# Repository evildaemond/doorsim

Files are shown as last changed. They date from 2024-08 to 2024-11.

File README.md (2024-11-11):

# doorsim

The DoorSim is a Open Source PACS (Physical Access Control System) built for research, training, and CTFs on RFID and Physical Security. 

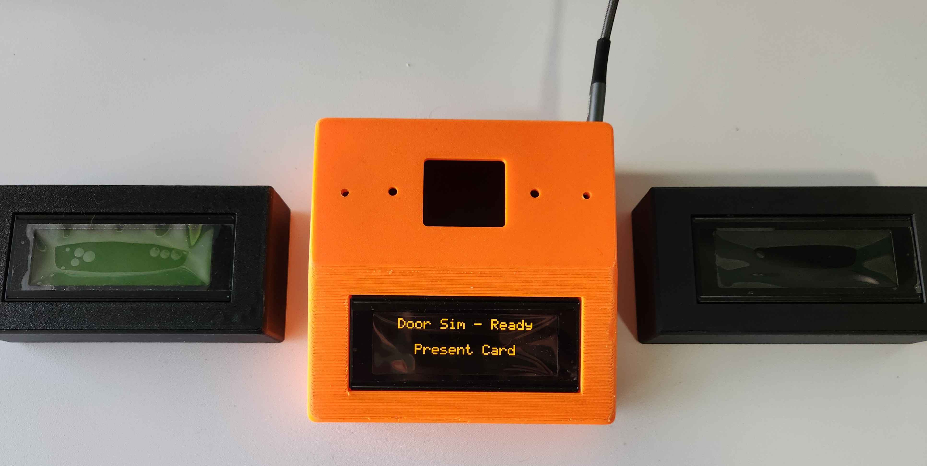
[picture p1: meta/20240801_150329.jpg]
doorsim


## Features

- Custom PCB with ESP32 Base
- Wiegand interface with Industry Standard Connectors
- 2004a Display for Ease of Reading
- Web Interface for Card/Event Reading and Settings
- Inbuilt CTF Mode with event logs
- USB-C PD Power Supply
- Expandable GPIO
- Multiple 3d Printed Desktop Reader Cases

## Bill of Materials

### PCB

|Quantity|Name|Link|
|---|---|---|
|1|PCB|Repo Link|
|1|ESP32-WROOM-32D Development Board|<https://www.aliexpress.com/item/1005006476877078.html>|
|1|2004A Display (Bare without i2c converter)|<https://www.aliexpress.com/item/1005005973980073.html?spm=a2g0o.order_list.order_list_main.22.3d051802PKVqRJ>|
|1|USB-C PD Trigger Board|<https://www.aliexpress.com/item/1005004381460387.html>|
|3|5.0-2P Screw Terminal Blocks|<https://www.lcsc.com/product-detail/Screw-terminal_Cixi-Kefa-Elec-KF332K-5-0-2P_C474889.html>|
|1|2.54mm 1x16 male-male header pins|<https://www.aliexpress.com/item/1005001514058091.html>|

### Cases

#### Handheld Version

|Quantity|Name|Link|
|---|---|---|
|1|Case Body||
|1|Case Bottom||
|2|M3 Standard CNC Kitchen Threaded Insert|https://cnckitchen.store/products/gewindeeinsatz-threaded-insert-m3-standard-100-stk-pcs|
|4|M4 Standard CNC Kitchen Threaded Insert|https://cnckitchen.store/products/gewindeeinsatz-threaded-insert-m4-standard-50-stk-pcs|
|4|M3x10 Round Head Screw||
|2|M4x10 Flat Head Screw||

#### All Others

|Quantity|Name|Link|
|---|---|---|
|1|Case Body||
|1|Case Bottom||
|2|M3 Standard CNC Kitchen Threaded Insert|https://cnckitchen.store/products/gewindeeinsatz-threaded-insert-m3-standard-100-stk-pcs|
|4|M4 Standard CNC Kitchen Threaded Insert|https://cnckitchen.store/products/gewindeeinsatz-threaded-insert-m4-standard-50-stk-pcs|
|2|M3 Nut||
|2|M3x12 Flat Head Screw||
|4|M3x10 Round Head Screw||
|4|M4x10 Flat Head Screw||

### RFID Reader

The design of the DoorSim at this stage means you can use any RFID Reader which supports Wiegand Output. The only difference will be the 3d printed case you house the doorsim in, only if you intend to use it as a non-handheld version. 

## Build Steps

### Soldering

Soldering guide assumes minimal soldering experience and only through hole construction

1. Collect all required items in Main Board Bill of Materials
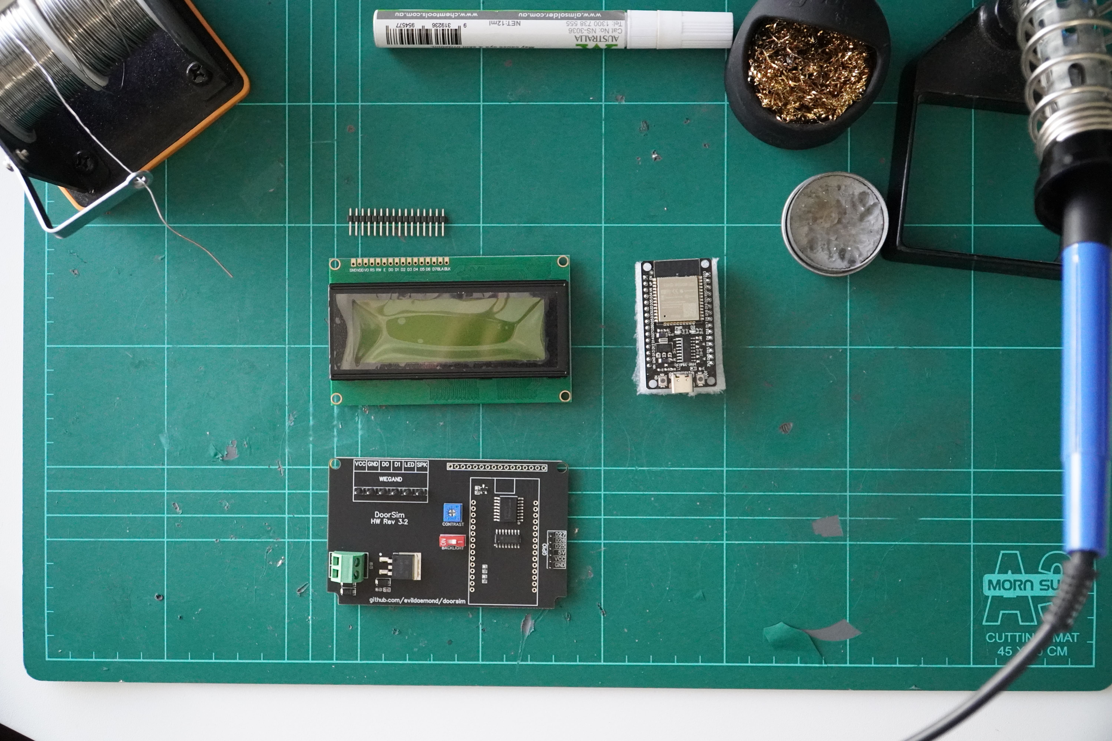
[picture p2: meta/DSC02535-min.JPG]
step1

1. Insert legs of the ESP32-WROOM-32D Development Board into PCB
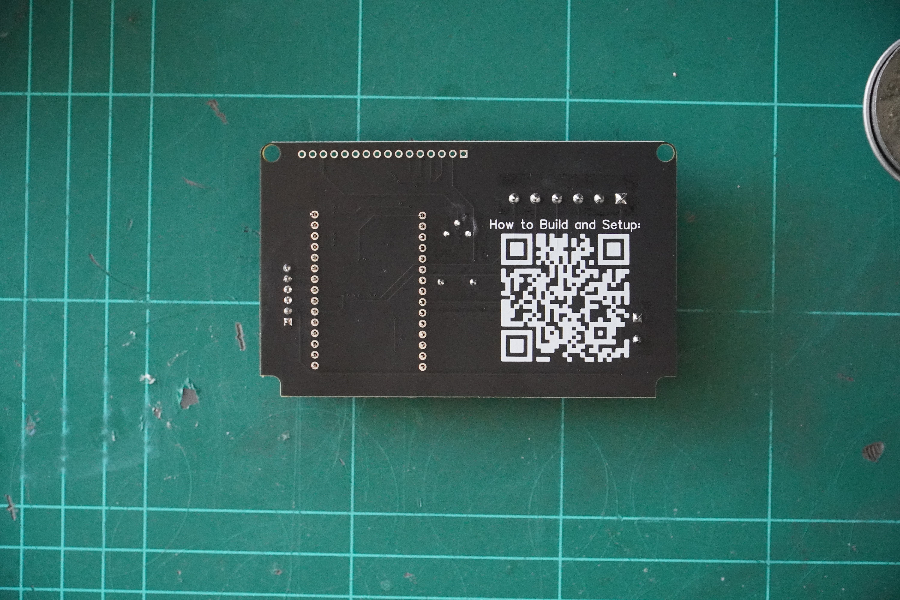
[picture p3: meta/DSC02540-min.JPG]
step2

1. Apply flux and solder legs in place, apply light pressure from the back on the development board and start at each corner, try to keep the board flat
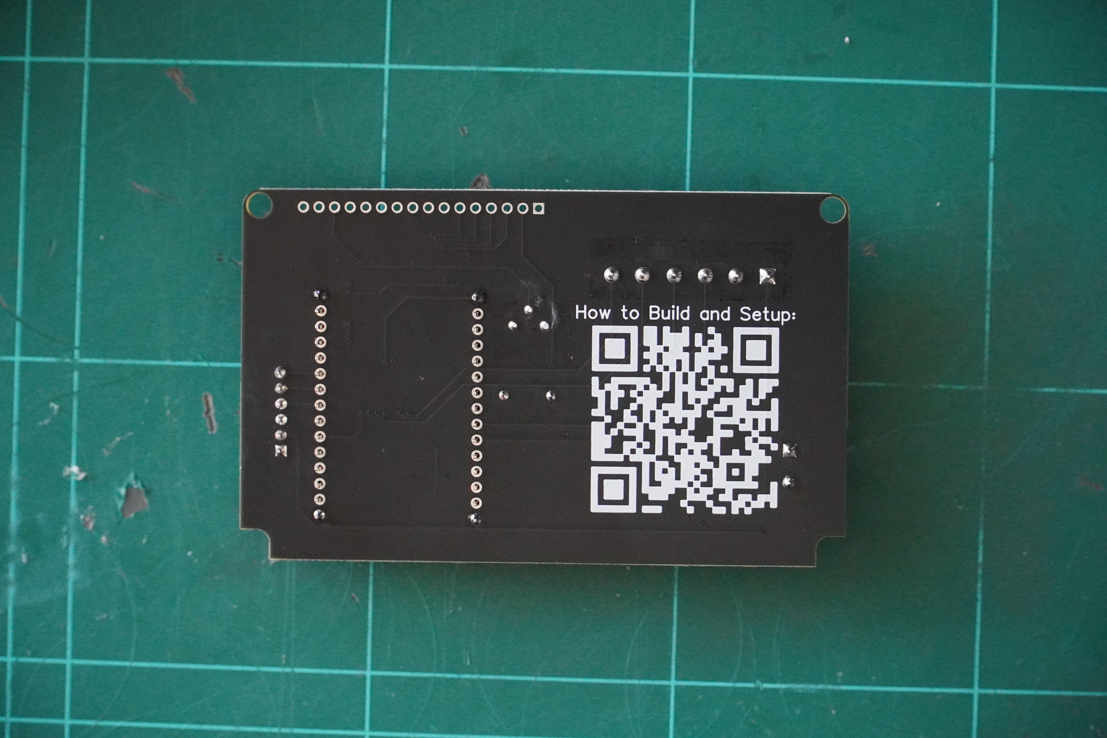
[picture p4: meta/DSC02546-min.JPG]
step3

1. Trim down the pins legs to roughly 2mm (078740157 Inches) and clean any leftover residue lightly with isopropyl alcohol and a old toothbrush
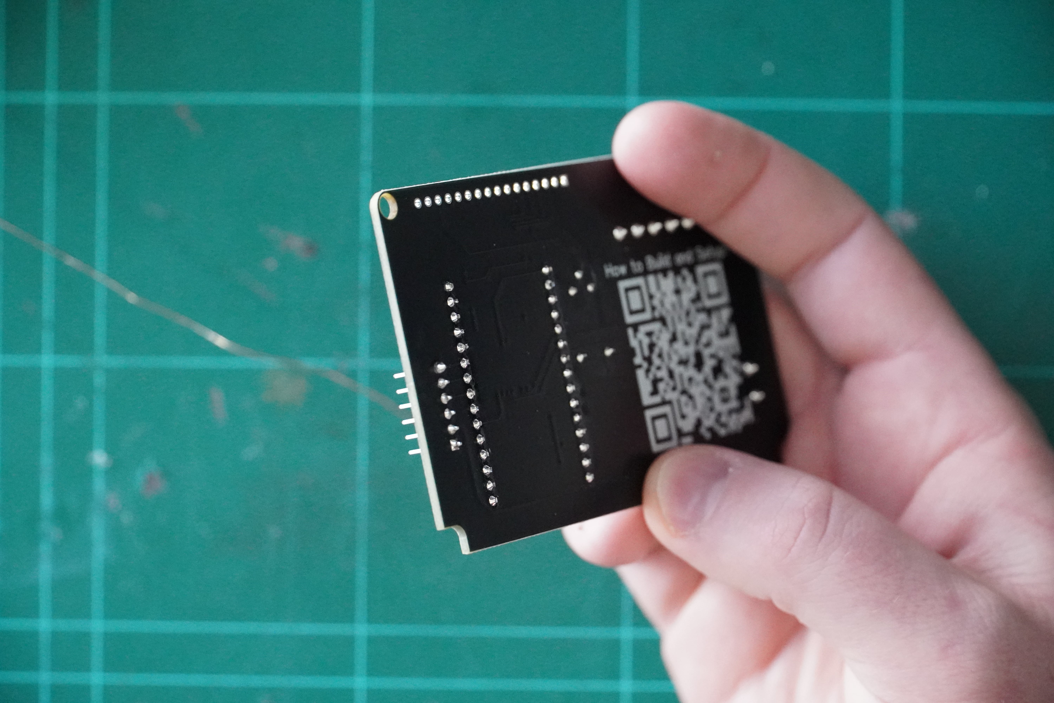
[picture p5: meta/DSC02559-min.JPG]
step4

1. Fit the male-to-male header pins between the 2004a display and the PCB, with the longer side facing up
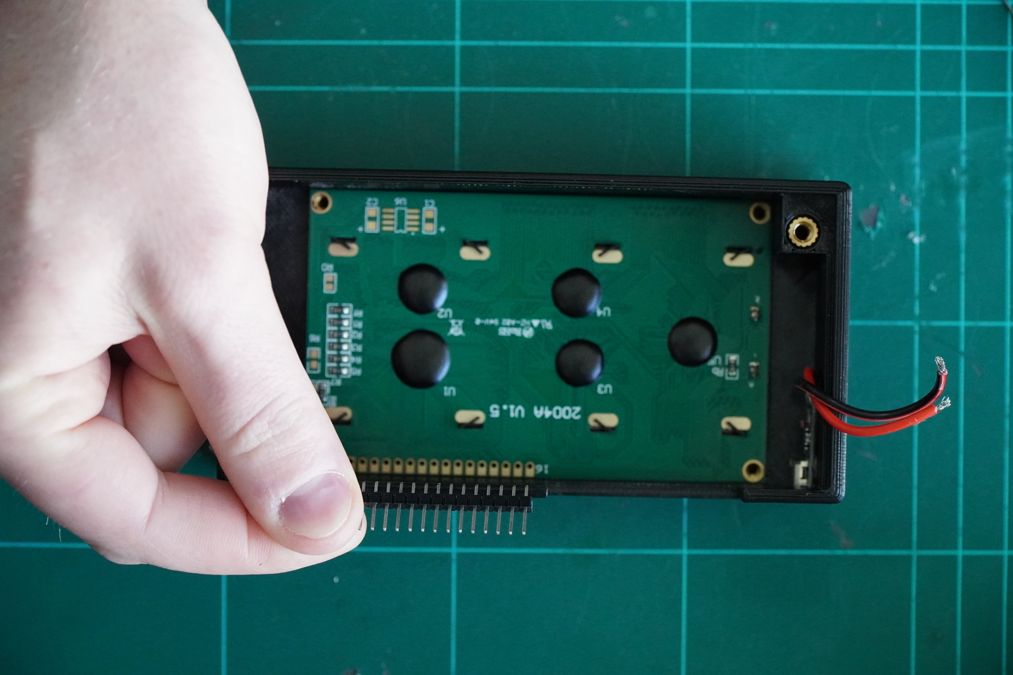
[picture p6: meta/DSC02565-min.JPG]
step5

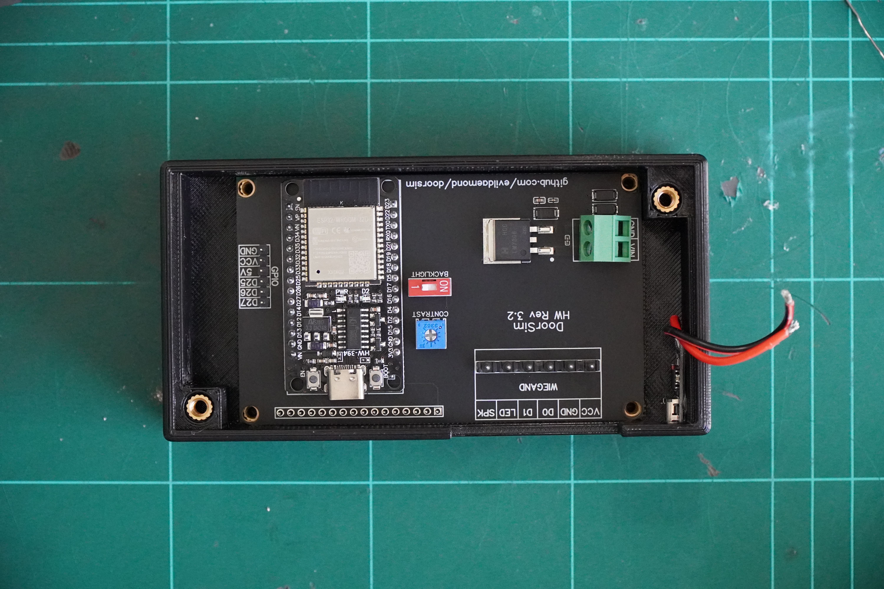
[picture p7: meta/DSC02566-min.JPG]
step6

1. Applying pressure to the left and top sides of the PCB and 2004a display, apply flux and solder the 2 pins of the opposing sides on the PCB. 
    1. Hint: They should be alligned with the holes on the board
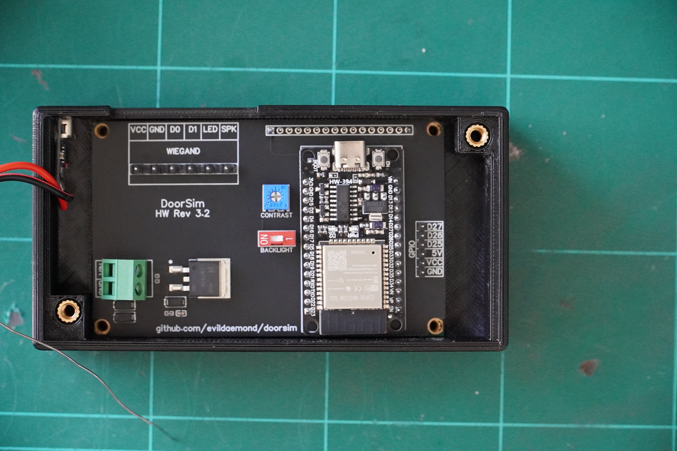
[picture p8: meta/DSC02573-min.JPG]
step7

1. Flip over the board, applying pressure on the same sides, and do the same on the 2004a display side.
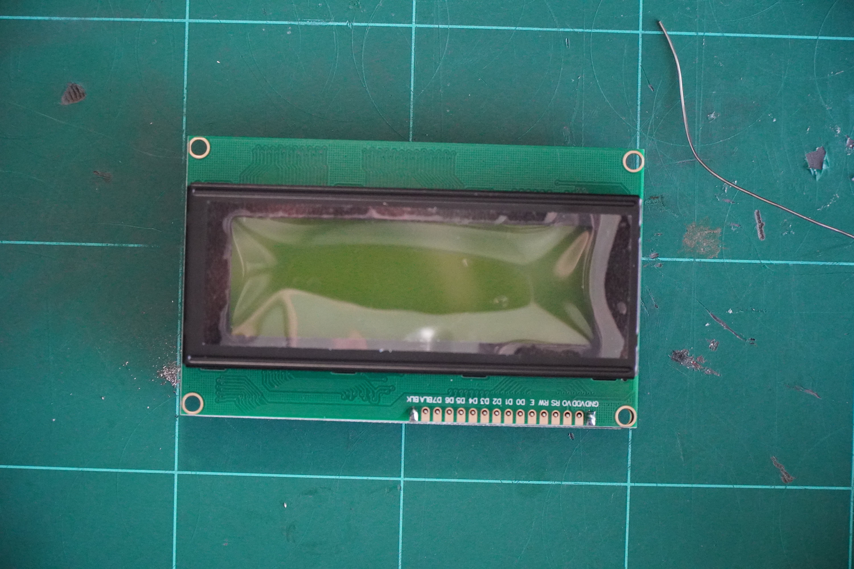
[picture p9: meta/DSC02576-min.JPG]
step8

1. Solder in the rest of the pins on both the display and PCB
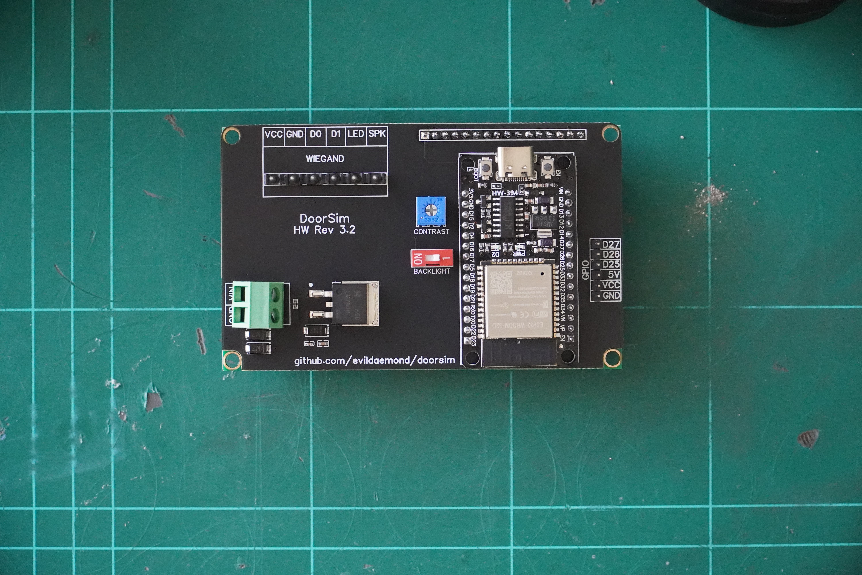
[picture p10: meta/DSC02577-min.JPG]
step9

1. Trim the PCB Side of the pin legs to roughly 2mm (078740157 Inches) and clean any leftover residue lightly with isopropyl alcohol and a old toothbrush
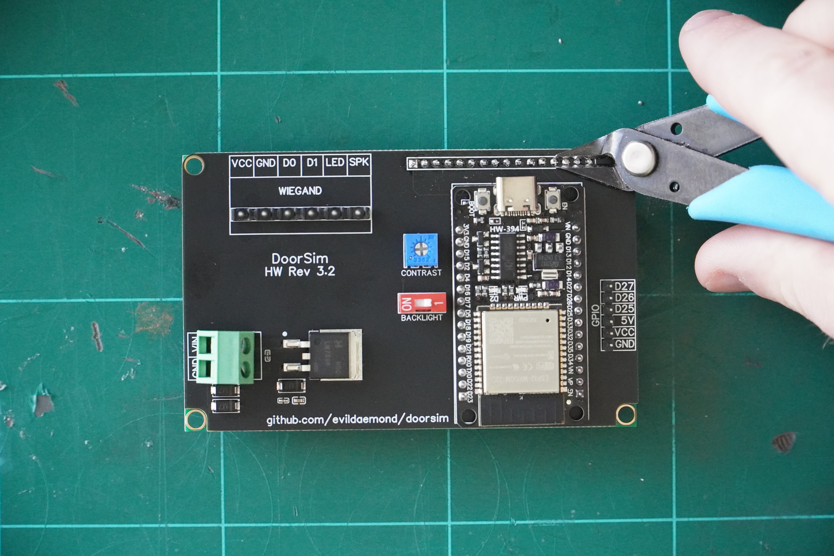
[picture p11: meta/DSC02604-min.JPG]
step10

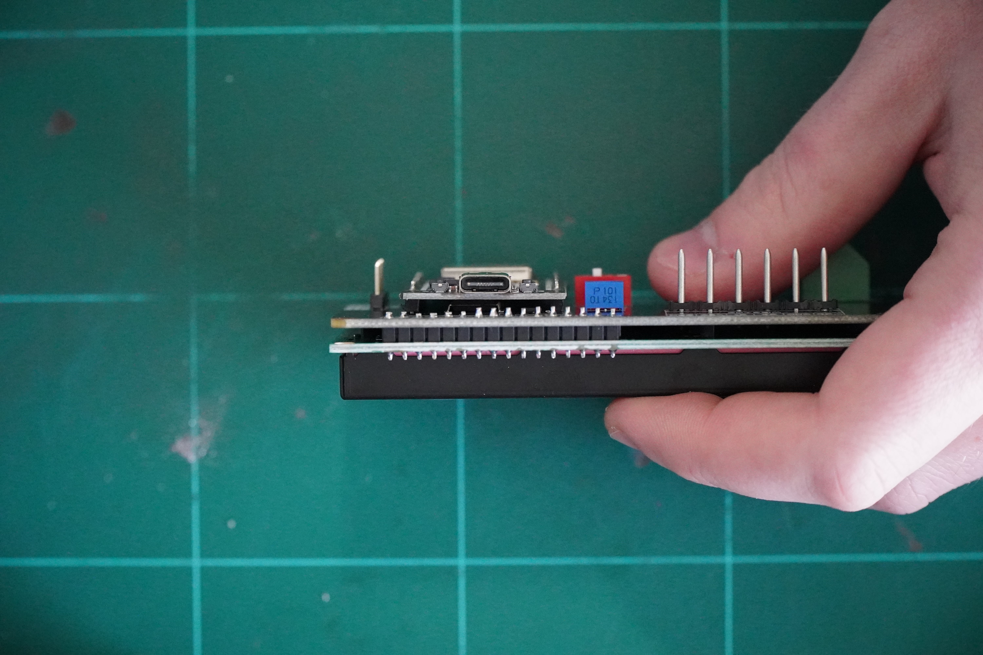
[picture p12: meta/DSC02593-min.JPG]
step11

1. *Optional:* In some cases, you may need to trim or elongate the wires for the USB-PD Connector, recommendation is to measure and cut, remove old wire connectors from board, and tin the ends before inserting and screwing into terminal connectors

### Case

1. Using the M3 Standard Threaded Insert, insert 4 into the 2004a Display hole, applying with a soldering iron, try to keep it straight up as you insert, applying light pressure
    1. Hint: Using a set of tweesers will help here 
1. Using the M4 Standard Threaded Insert, insert them into the case posts, applying with a soldering iron, try to keep it straight up as you insert, applying light pressure

### Programming

1. Install Arduino IDE
1. Install Requirements
    1. ESP32 Board Manager
    2. [ArdunioJson by Benoit Blanchon](https://arduinojson.org/)
    3. [AsyncTCP by dvarrel](https://github.com/dvarrel/AsyncTCP)
    4. [ESPAsyncWebServer by Me-No-Dev](https://github.com/me-no-dev/ESPAsyncWebServer)
    5. [LiquidCrystal_I2C](https://github.com/fdebrabander/Arduino-LiquidCrystal-I2C-library)
1. Git Clone and Open File
1. Choose Board, Choose Port
1. Click Upload
1. If required, when reached connecting, Hold Boot button
1. Once Complete, unplug device

### Fixtures

#### USB-PD

1. Using either hot glue or double sided tape, apply the tape to the back of the PCB for the USB-PD Adaptor, and apply it to the hole for the USB-PD Adaptor (It may require a small amount of extra force to do this)
    1. In the handheld design, this can be hard due to the space, inserting from the front instead is also an option

#### PCB

1. Mount the PCB to the case of your choice, using 4 x M3x10 Round Head Screws (Preferabily Hex keyed)
1. Attach the USB-PD Leads to your screw terminal, with the Red being screwed into VIN, and the Black and Red stripe to GND
1. Insert the cables for your RFID reader into the Screw Terminal Blocks, using the supplied wiring diagram for your RFID Reader, then insert it into your PCB

#### Case

1. Attach your RFID Readers mounting bracket using M3x12 M3x12 Flat Head Screws (Preferabily Hex keyed) and M3 Nuts (Washers can be used, but should be fine without)
1. Attach the Case Bottom to the Case using M4x10 Flat Head Screws (Preferabily Hex keyed) which can be screwed into the heat-set threaded inserts

### Testing

1. Unscrew the case bottom, exposing the PCB
1. Plug in a USB-PD Capible connector, such as a laptop charger
1. Flick the Backlight Switch from OFF to ON (may be marked as 1 instead of OFF), you should see the displays backlight turn on
1. Using a small flathead screwdriver, rotate the Contrast Potentiomiter to the right until the display reads well for you
    1. If it feels too dark, or is hard to read, ajusting this sensor will fix that
1. Using a device with Wifi access, check for the Wireless Access Point "Doorsim", by default, this should have no password
1. Connect to the Wifi Network, and verify that the network can be accessed, and browse to `http://192.168.4.1`
    1. Note: This may have issues on phones, this is how Android/iOS works with these networks, as they do not have internet.

## Use

### Web Interface

- Accessable via Wifi Network Broadcasting on ESP32
    - Can be configured via the Settings menu on the Web Interface
- Browse to `http://192.168.4.1`
- Last Swiped Card Interface, displaying card information
    - Hint: Click on the Hex Code for the Card to copy it to clipboard
- CTF Board will show the CTF interface, alongside the additional cards to be added, and the last swiped cards
    - Hint: CTF Configurations can be imported and exported using the buttons avalible
- Settings menu allows you to change basic settings of the device

### Display

- Displays generic messaging or CTF messaging based upon enabled mode
    - Can be configured via the Settings menu on the Web Interface
- Displays either the card information of the last swiped card or the invalid/valid response of a card

### Modes

#### CTF Mode

- Presents Generic Message for DoorSim on Display
- Can be customised
- Displays Incorrect for cards not found in device
- Web Interface shows all data in Last Swiped Cards 
- Web Interface CTF Board will show CN/FC of last invalid card swiped, shows users authorised with only their name

#### Demo Mode

- Presents Generic Message for DoorSim on Display
- Display the Card Number and Facility Code for each card scanned on the 2004a display
- Web Interface shows all data in Last Swiped Cards 
- Web Interface CTF Board will show HEX of cards swiped

## Screenshots

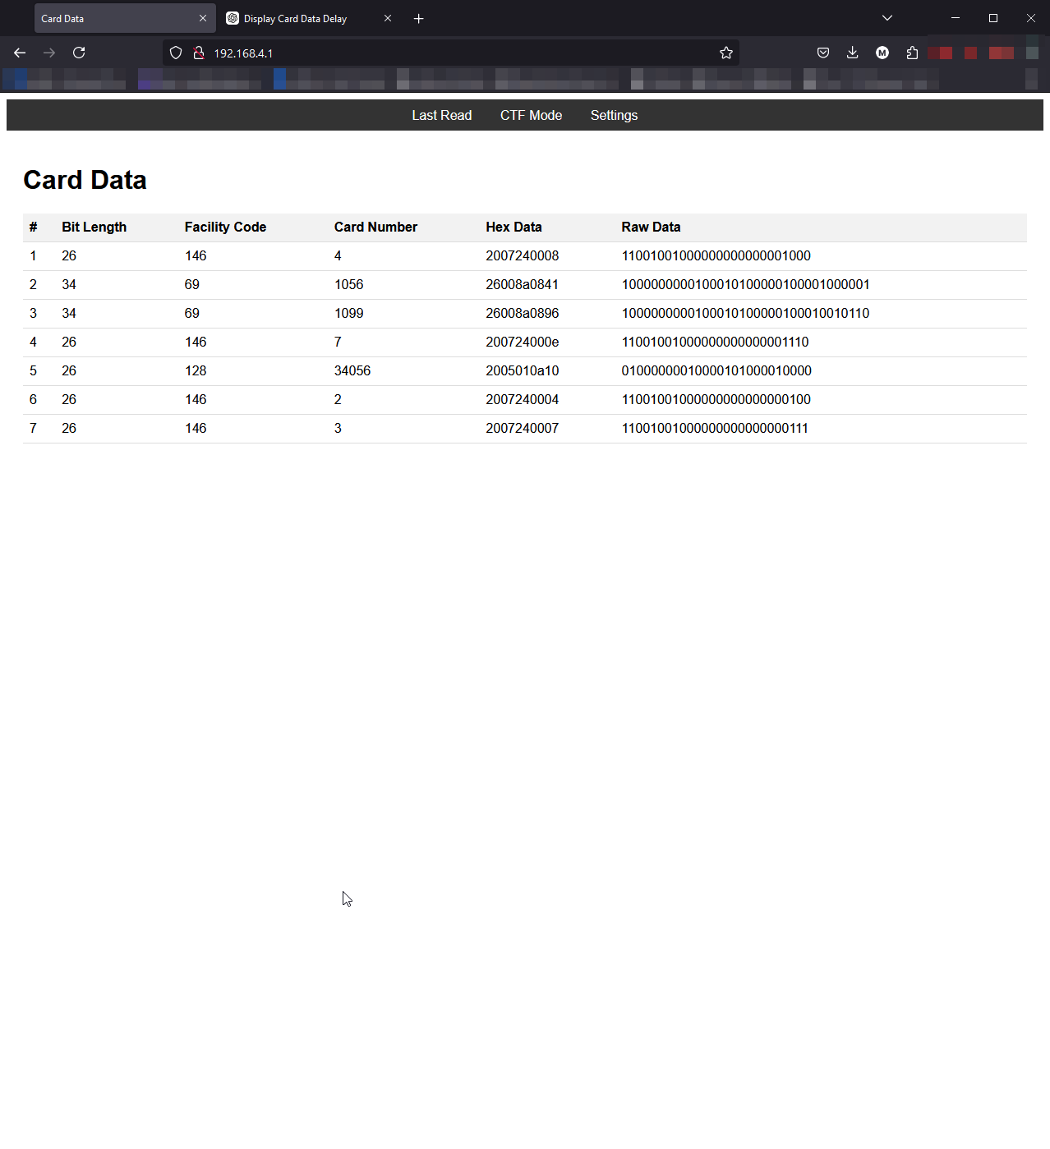
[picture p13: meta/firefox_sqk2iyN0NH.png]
Last Read Card Info

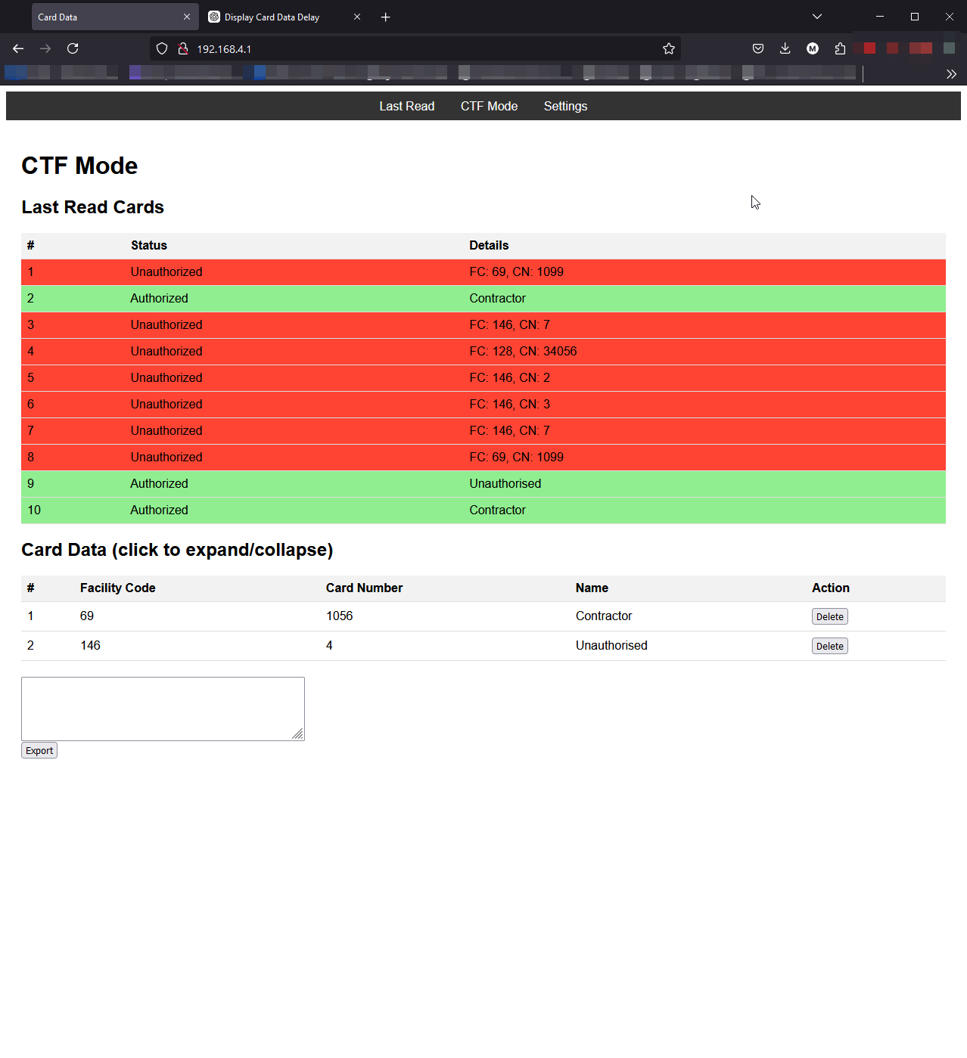
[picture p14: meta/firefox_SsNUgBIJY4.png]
CTF Display

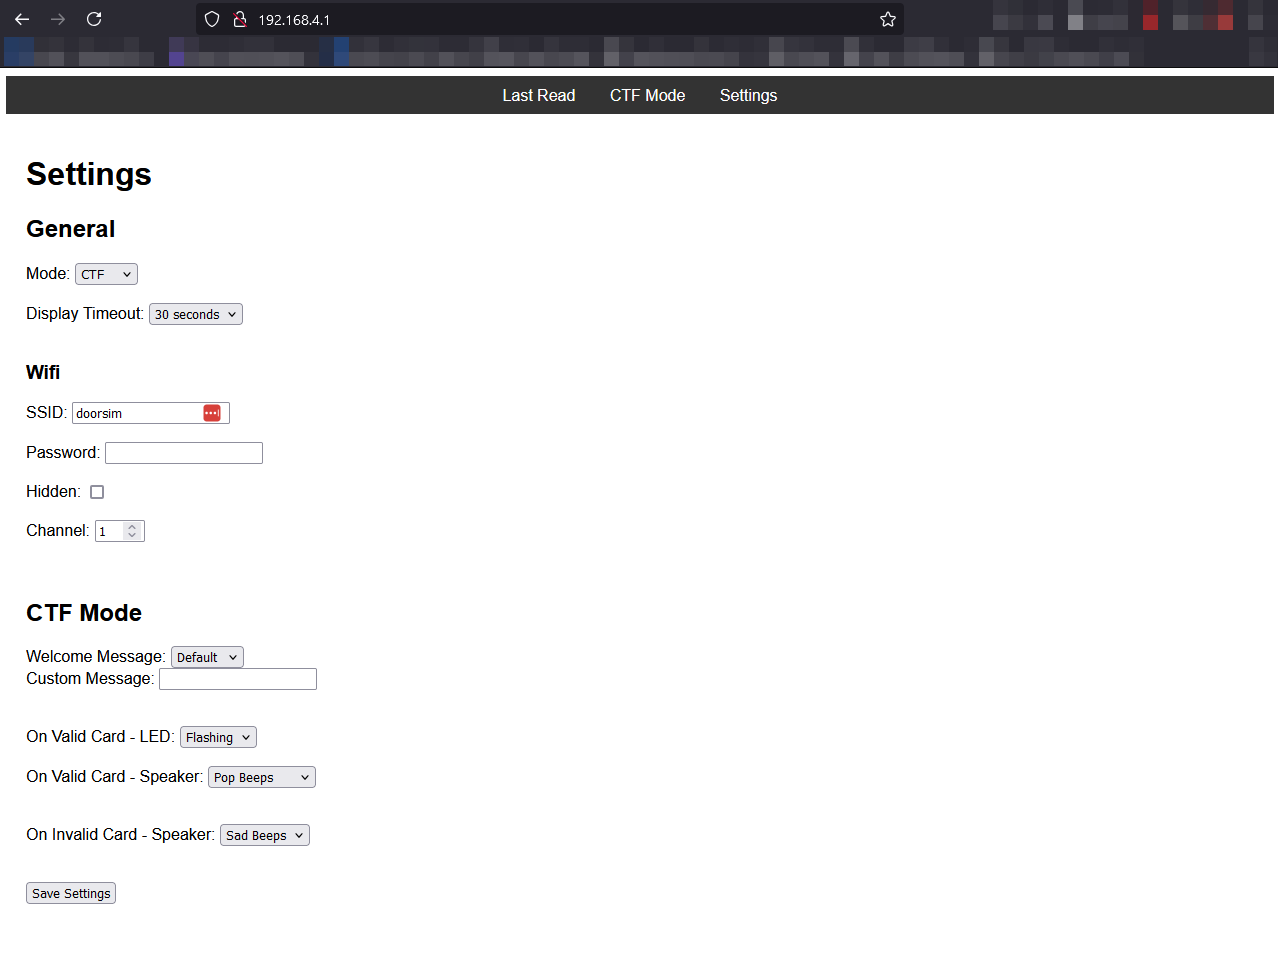
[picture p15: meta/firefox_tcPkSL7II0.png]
Settings Menu


## Acknowledgements

- Core Weigand and card decoding based upon [Tusk](https://github.com/TeamWalrus/tusk) 
- Design inspiration by [RTA Door Simulator](https://shop.redteamalliance.com/products/rfid-hacking-and-defense-physical-access-control-systems-pacs-proxmark3-training)

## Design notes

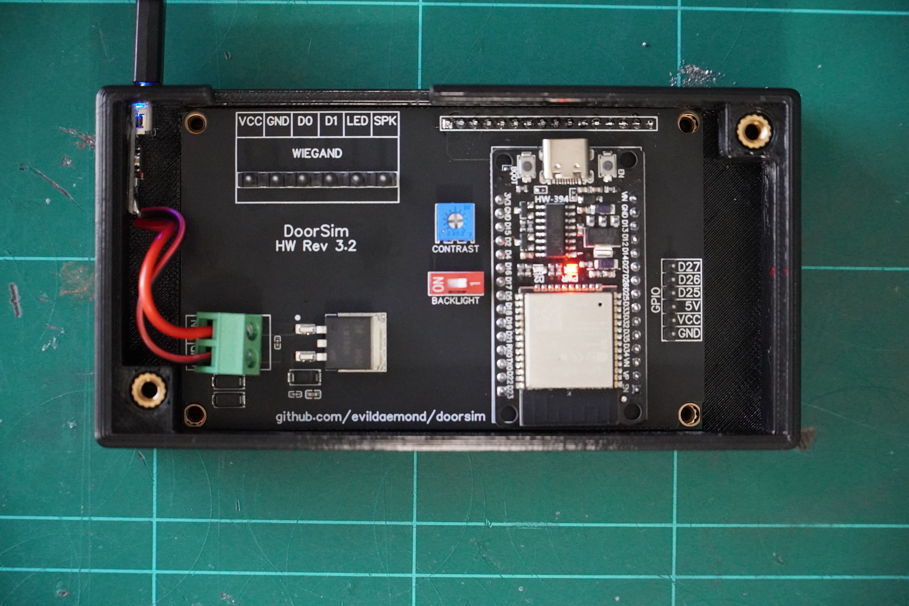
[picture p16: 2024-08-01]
meta/DSC02608-min.JPG

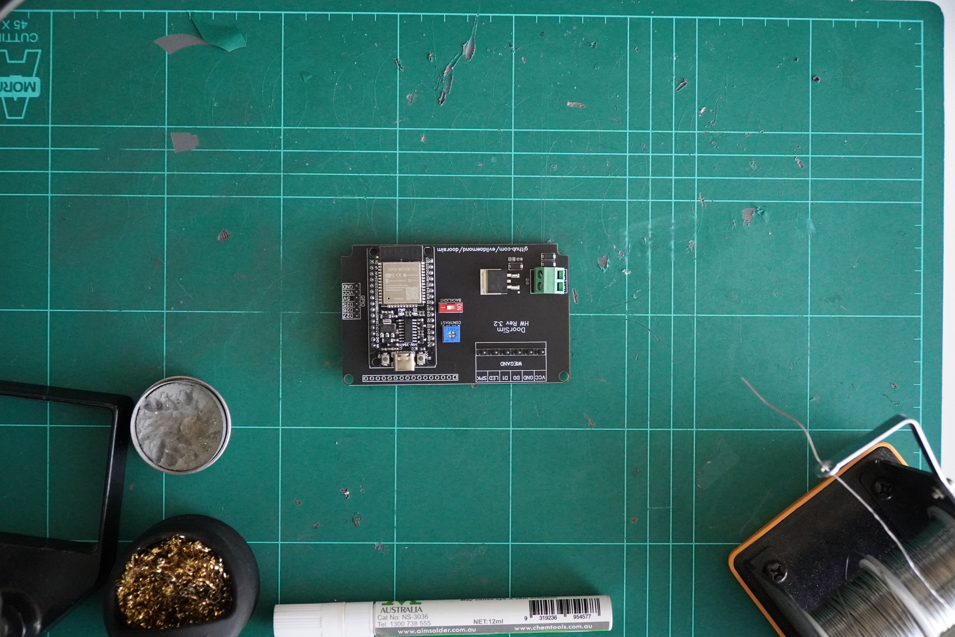
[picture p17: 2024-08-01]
meta/DSC02537-min.JPG

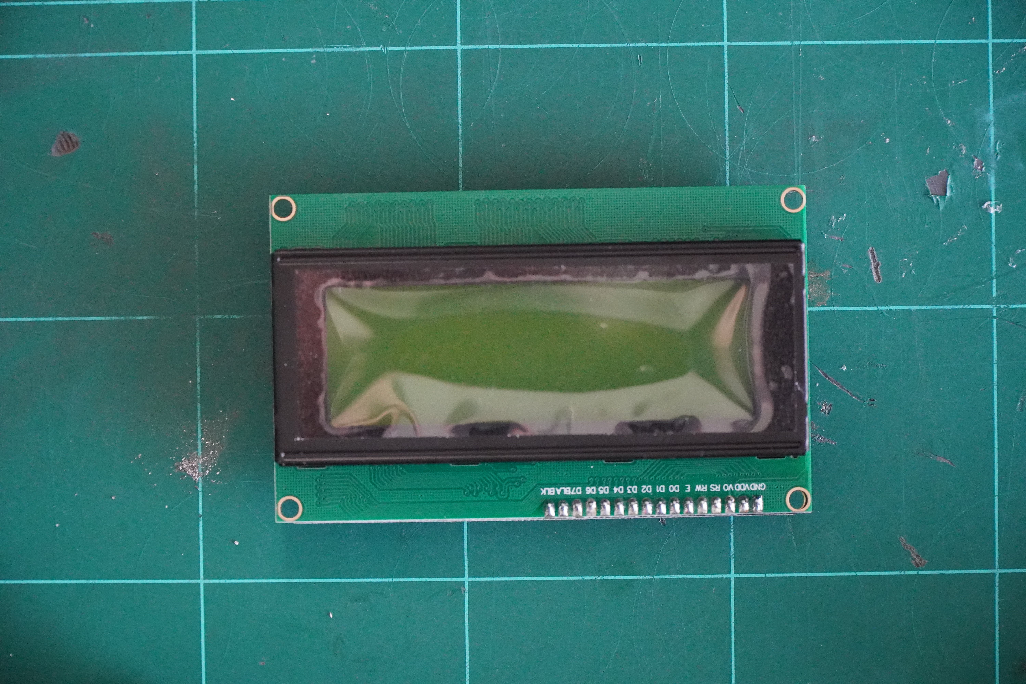
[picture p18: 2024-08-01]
meta/DSC02589-min.JPG

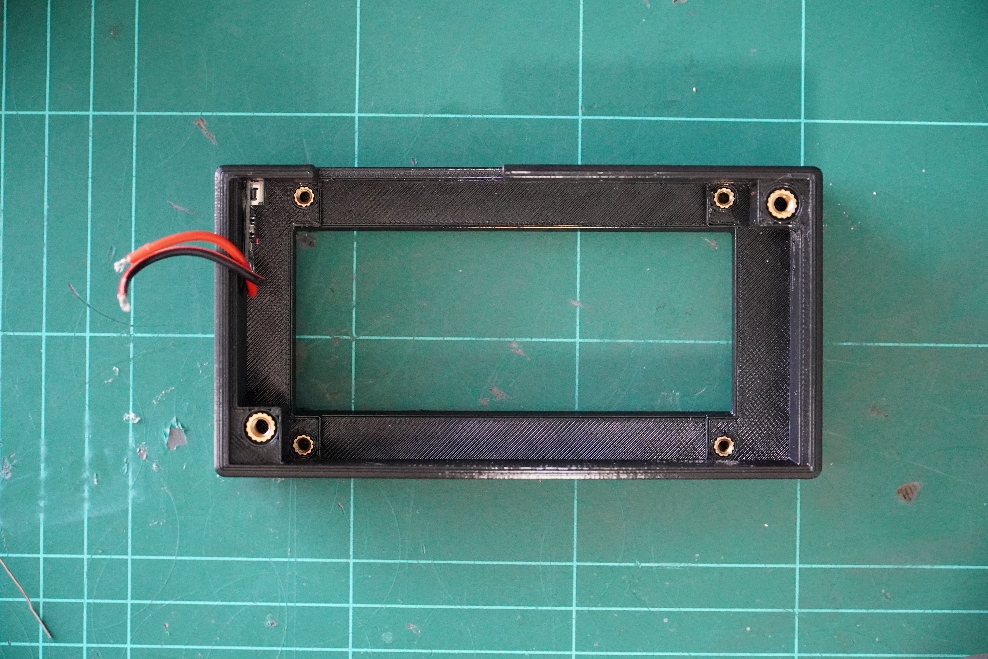
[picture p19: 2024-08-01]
meta/DSC02562-min.JPG

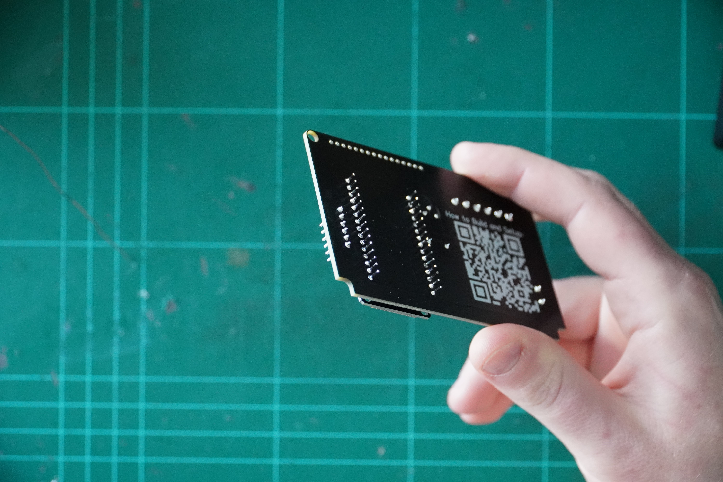
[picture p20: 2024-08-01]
meta/DSC02551-min.JPG

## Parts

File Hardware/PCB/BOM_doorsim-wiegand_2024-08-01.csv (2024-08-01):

ID | Name | Designator | Footprint | Quantity | Manufacturer Part | Manufacturer | Supplier | Supplier Part | Price | Pins | 3DModel | Contributor | JLCPCB Part Class | Resistance(Ohms) | image | link
1 | LM7806D2TRG | U1 | TO-263-2_L10.2-W8.7-P5.08-LS15.1-BL | 1 | LM7806D2TRG | HGC(深圳汉芯) | LCSC | C5145271 | 0.169 | 3 | TO-263-2_L10.2-W8.7-P5.08-LS15.1-BL | lcsc |  |  |  | https://atta.szlcsc.com/upload/public/pdf/source/20200707/C696592_CC6BE80D3E52E2C8F885C01C750139D0.pdf
2 | PZ2.54-1*16 | 2004A | HDR-TH_16P-P2.54-V-M | 1 | PZ2.54-1*16 | ZHOURI(洲日) | LCSC | C5360903 | 0.078 | 16 | HDR-TH_16P-P2.54-M-LI-1X16P | lcsc |  |  |  | https://item.szlcsc.com/614820.html?ref=editor&logined=true
3 | 1uF | C1 | C0603 | 1 | CL10A105KO8NNNC | SAMSUNG(三星) | LCSC | C1592 | 0.003 | 2 | C0603_L1.6-W0.8-H0.8 | lcsc | Extended Part |  |  | https://item.szlcsc.com/362304.html
4 | 330nF | C2 | C0402 | 1 | V334K0402X5R250NNT | VIIYONG(微容) | LCSC | C609906 | 0.007 | 2 | C0402_L1.0-W0.5-H0.5 | LCSC | Extended Part |  |  | https://item.szlcsc.com/15869.html
5 | 100nF | C3 | C0402 | 1 | CL05B104KO5NNNC | SAMSUNG(三星) | LCSC | C1525 | 0.001 | 2 | C0402_L1.0-W0.5-H0.5 | lcsc | Basic Part |  |  | https://item.szlcsc.com/15869.html
6 | Header-Male-2.54_1x6 | GPIO | HDR-TH_6P-P2.54-V-M-1 | 1 | 2.54-1x6P直针 | BOOMELE(博穆精密) | LCSC | C37208 | 0.027 | 6 | HDR2.54-M-LI-1X6P | lcsc | Extended Part |  |  | https://item.szlcsc.com/38187.html
7 | 2n3904S-RTK/PS_C18536 | Q1 | SOT-23-3_L2.9-W1.3-P1.90-LS2.4-TR | 1 | 2n3904S-RTK/PS | KEC | LCSC | C18536 | 0.012 | 3 | SOT-23-3P_L2.9-W1.3-H1.0-LS2.4-P0.95 | lcsc | Extended Part |  | //image.lceda.cn/szlcsc/C18536.jpg | https://item.szlcsc.com/70837.html
8 | 4.7K | R4,R5,R6 | R0603 | 3 | AECR0603F4K70K9 | ResistorToday | LCSC | C328364 | 0.001 | 2 | R0603_L1.6-W0.8-H0.8 | LCSC |  |  |  | https://item.szlcsc.com/137208.html
9 | PCF8574T/TR | U2 | SO-16_L10.3-W7.5-P1.27-LS10.3-BL | 1 | PCF8574T/TR | HGSEMI(华冠) | LCSC | C2987288 | 0.69 | 16 | SO-16_L10.3-W7.5-P1.27-LS10.3-BL | lcsc | Extended Part |  |  | https://atta.szlcsc.com/upload/public/pdf/source/20210601/C604672_B8908D53C75E35765CA9E0FF6AB80524.pdf
10 | DG411DY-T1-E3 | U3 | SOIC-16_L9.9-W3.9-P1.27-LS6.0-BL | 1 | DG411DY-T1-E3 | VISHAY(威世) | LCSC | C17218 | 0.94 | 16 | SOIC-16_L9.9-W3.9-H1.8-LS6.0-P1.27 | lcsc | Extended Part |  |  | http://datasheet.octopart.com/MC14076BDR2G-ON-Semiconductor-datasheet-608107.pdf
11 | 964-T-DS/02 | U4 | CONN-TH_2P-P5.08_WECO_964-T-DS-02 | 1 | 964-T-DS/02 | WECO(威克德诺) | LCSC | C2974854 | 0.872 | 2 | CONN-TH_2P-P5.08_WECO_964-T-DS-02 | LCSC | Extended Part |  |  | https://www.alliedelec.com/m/d/56d4e319026393ce9a253dd380932eaf.pdf
12 | M7_C2902910 | U5,U7,U9 | SMA_L4.5-W2.7-LS5.1-RD | 3 | M7 | MSKSEMI(美森科) | LCSC | C2902910 | 0.005 | 2 | SMA_L4.5-W2.7-LS5.1-RD | lcsc | Extended Part |  |  | https://atta.szlcsc.com/upload/public/pdf/source/20190401/C383695_AEF52A03E65B0BD1909510AEF3755E3F.pdf
13 | 971-SLR-THR-1,3/06 | WIEGAND | HDR-TH_6P-P5.00-V-M | 1 | 971-SLR-THR-1,3/06 | WECO(威克德诺) | LCSC | C7462054 | 0.645 | 6 | HDR-TH_6P-P5.00-V-M | lcsc | Extended Part |  |  | https://www.wecoconnectors.com/wp-content/uploads/2019/10/971-SLR-THR-1.1_en.pdf
14 | 100Ω | CONTRAST | RES-ADJ-TH_3362P-1-104LF | 1 | 3362P-1-101LF | BOURNS | LCSC | C81265 | 0.526 | 3 | RES-ADJ-TH_3362P-1-104LF | 立创EDA官方封装库 | Extended Part | 100 |  | https://item.szlcsc.com/82416.html
15 | DSWB01LHGET | BACKLIGHT | SW-TH_DSWB01LHGET | 1 | DSWB01LHGET | KE | LCSC | C126888 | 0.161 | 2 | SW-TH_2P-L4.1-W9.9-H5.4-P2.54 | 立创EDA官方封装库 |  |  |  | https://item.szlcsc.com/138168.html

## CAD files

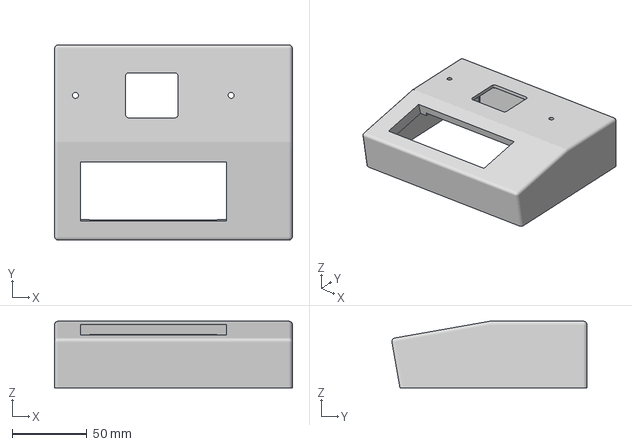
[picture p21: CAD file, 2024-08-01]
Hardware/3DPrints/DoorSim-LongboyMain.3mf
159.0 x 130.5 x 44.5 mm

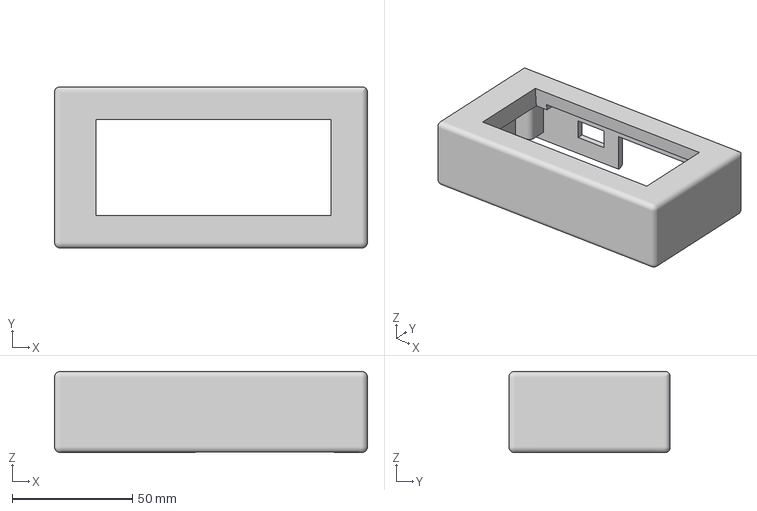
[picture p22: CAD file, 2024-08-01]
Hardware/3DPrints/DoorSim-HandheldMain.3mf
130.0 x 67.0 x 33.8 mm

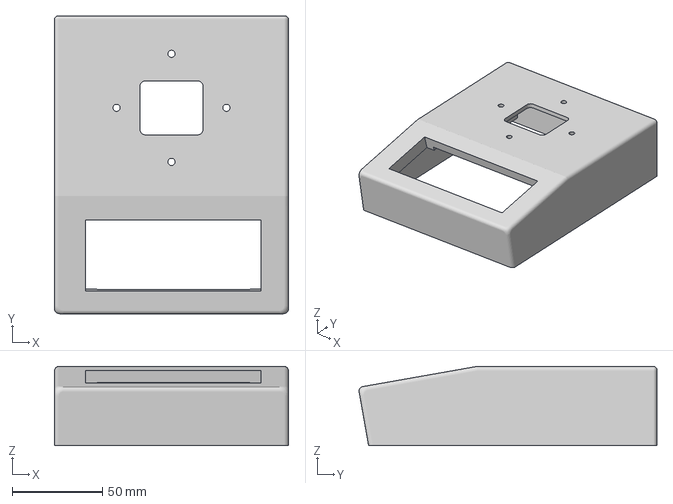
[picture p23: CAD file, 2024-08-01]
Hardware/3DPrints/DoorSim-MaxMain.3mf
130.0 x 165.5 x 44.0 mm

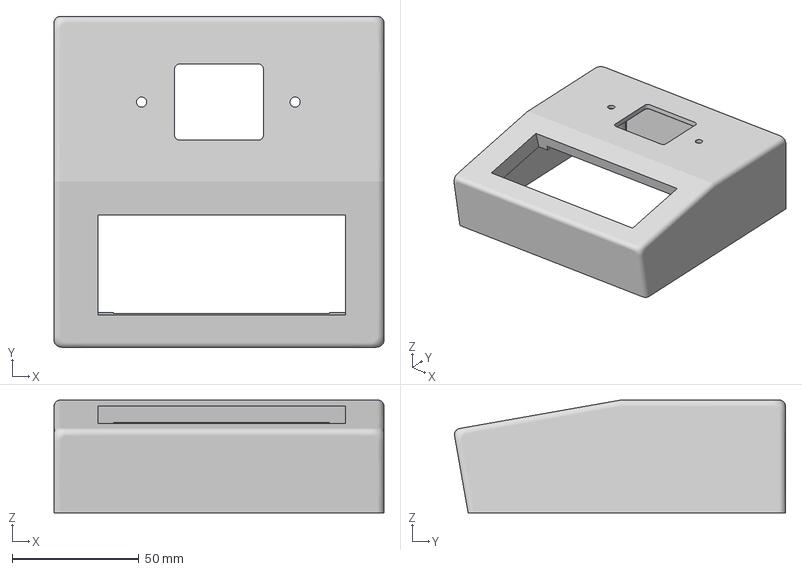
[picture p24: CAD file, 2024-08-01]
Hardware/3DPrints/DoorSim-RegularMain.3mf
130.0 x 130.5 x 44.5 mm

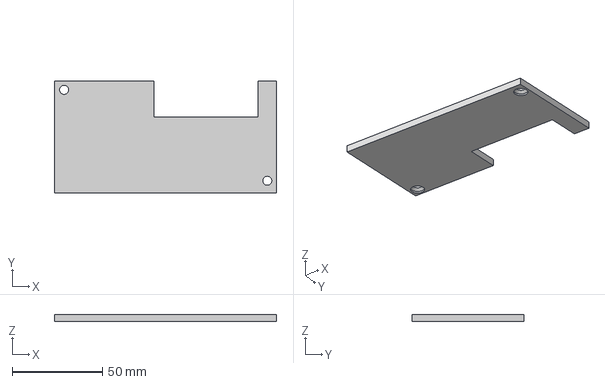
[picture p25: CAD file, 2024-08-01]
Hardware/3DPrints/DoorSim-HandheldBottom.3mf
123.0 x 62.3 x 4.00 mm

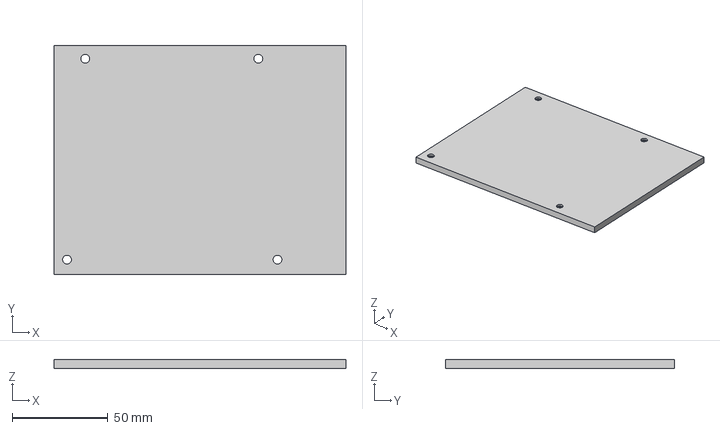
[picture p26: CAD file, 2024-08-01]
Hardware/3DPrints/DoorSim-LongboyBottom.3mf
152.6 x 119.5 x 4.50 mm

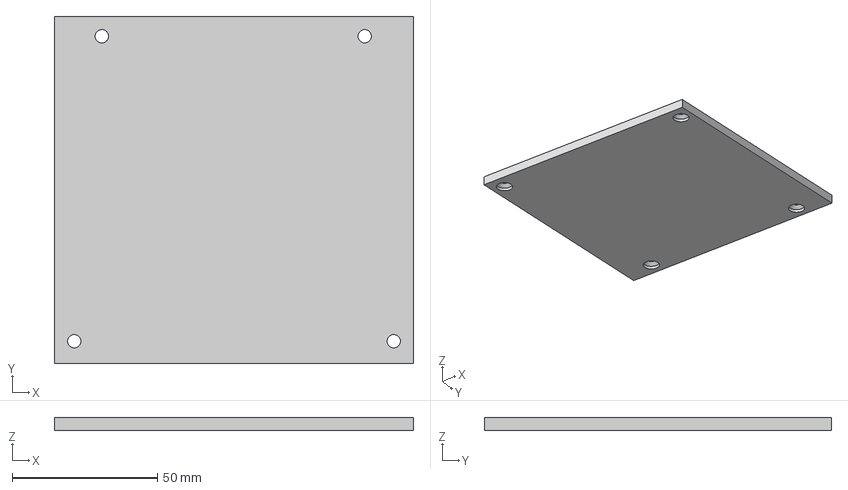
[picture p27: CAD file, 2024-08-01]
Hardware/3DPrints/DoorSim-RegularBottom.3mf
123.6 x 119.5 x 4.50 mm

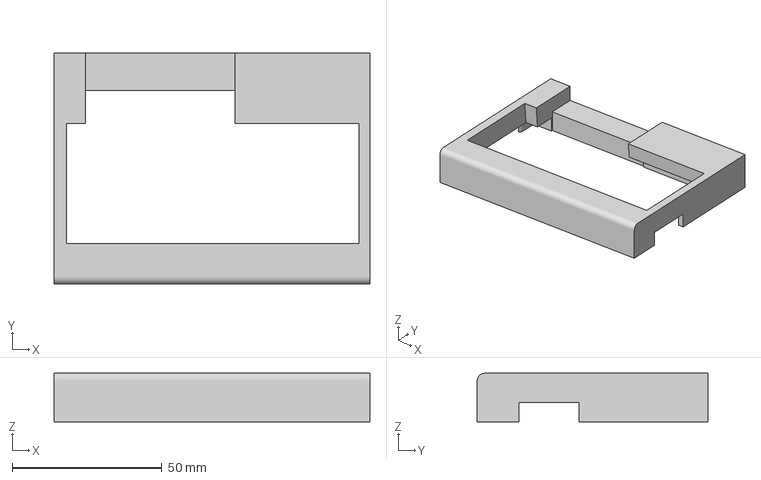
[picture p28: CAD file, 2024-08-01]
Hardware/3DPrints/SolderHelper.3mf
105.5 x 77.0 x 16.2 mm

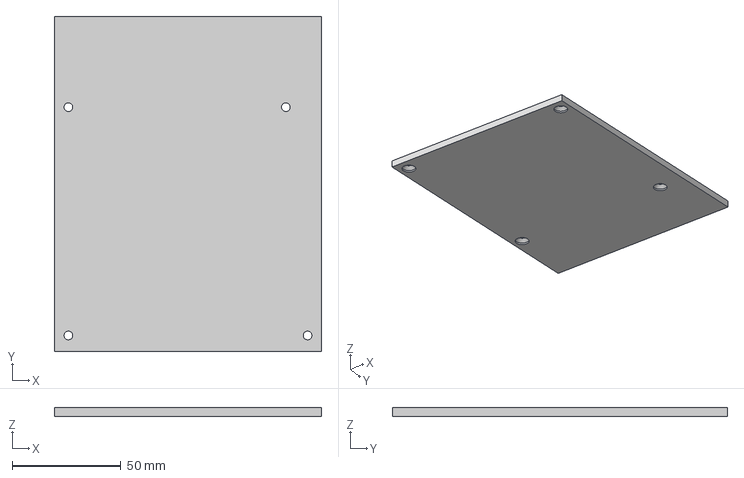
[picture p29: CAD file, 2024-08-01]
Hardware/3DPrints/DoorSim-MaxBottom.3mf
123.0 x 154.1 x 4.00 mm

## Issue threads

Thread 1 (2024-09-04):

RFID Card Reader Model

xdnewlun1, 2024-09-04:
Sorry If I missed this in the README but what RFID card reader was used for this project? I am gathering a list of what I need to purchase and want to make sure I get the right thing. I dont see any specific model mentioned in the build instructions, just a vague reference to RFID reader.

Thank you in advanced.

evildaemond, 2024-09-06:
Hey there,

You can use any RFID reader which outputs in wiegand format. The 3D printed cases are designed for multiple types of RFID Reader profiles, the major vendor dimensions, but the handheld can use any of them.

Closed 2024-09-06.

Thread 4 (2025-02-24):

WiFi in Client mode.

spankywetfish, 2025-02-24:
Just a question really, have you tried this "successfully" in WiFi client mode or just in AP mode ?
The reason I'm asking is I was thinking about adding other notification methods (e.g. slack webhook or similar), for no reason other than it's something to do.

I made a couple of minor changes to make the ESP32 available on a local network and it connects just fine.
The IP is output to the LCD and Serial prior to the welcome messages and I can access the Web UI no problem.
It then sites waiting for a card to be swiped as usual.
However for some reason, swiping a card doesn't register, there is the usual beep and LED flash but no serial or web notifications.
I'm a tad perplexed how such a simple change could interfere with the card swipe functionality, unless client mode WiFi some how interferes with the data pins connected with the reader ¯\_(ツ)_/¯

If you wanted to try this out, this is all I did.

Added consts for ssid and password then modified the setupWifi function as follows...

```
void setupWifi() {
  WiFi.begin(ssid, password);
  WiFi.setSleep(false);
  lcd.clear();
  lcd.setCursor(0, 0);

  while (WiFi.status() != WL_CONNECTED) {
    delay(500);
    Serial.print(".");
    lcd.print("*");
  }

  const String local_ip = WiFi.localIP().toString();
  Serial.println("");
  Serial.println("WiFi connected");
  Serial.print(local_ip);
  lcd.clear();
  lcd.setCursor(0, 0);
  lcd.print(centerText("WiFi connected", 20));
  lcd.setCursor(0, 2);
  lcd.print(centerText(local_ip, 20));
  delay(5000);
}
```

spankywetfish, 2025-02-26:
I've made a little progress in troubleshooting this.
It seems that any calls to a WiFi function borks the ability to read cards.
As an example reverting back to the original code, I added a line to output the AP IP address after initialisation.

e.g.
 ```
void setupWifi() {
  WiFi.softAP(ap_ssid, ap_passphrase, ap_channel, ssid_hidden);
  Serial.println(WiFi.softAPIP().toString());
}
```
and this breaks the ability to read cards.

So any of the WiFi functions in the previous post could cause this to bork, be it, `setSleep`, `status` or `localIP`, without which making a client connection becomes a tad onerous.

spankywetfish, 2025-03-04:
I've done a bit more work on this and it appears to be a memory/storage issue.
After adding additional fields to the web page and subsequent code for the ssid and passphrase of an AP to connect to in STA mode, I hit the same issue of not being able to read cards, this time in the original AP mode.

I commented out all the code I had added and then line by line re-added them, eventually hitting the last two lines of added code that read the stored STA SSID and Passphrase from preferences.
I then set about trying to compress the code as much as possible, this meant removing excess whitespace from the html/javascript section amongst other things.
My last compile resulted in...
```
Sketch uses 1053080 bytes (80%) of program storage space. Maximum is 1310720 bytes.
Global variables use 60104 bytes (18%) of dynamic memory, leaving 267576 bytes for local variables. Maximum is 327680 bytes.
```
which is roughly 6k less than the original code...
```
Sketch uses 1059296 bytes (80%) of program storage space. Maximum is 1310720 bytes.
Global variables use 60072 bytes (18%) of dynamic memory, leaving 267608 bytes for local variables. Maximum is 327680 bytes.
```
With this more compacted version I have successfully achieved a connection in STA mode while maintaining the ability to read cards/displaying them on the LCD and web page.
It's still not ideal as you have to have visibilty of your DHCP server in order to know what IP the web page will be visible on, but it's functional.

Next on the agenda is callouts to slack or maybe HA to switch on/off a light when a card is successfully swiped, but i fear that will increase the resource usage yet more and subsequently break card reading again.

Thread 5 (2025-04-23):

I2C pullup issue

tcccorp, 2025-04-23:
Hello,

I think there is a trouble on the PCB.

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

on this picture, we can see pullup resistors for I2C but for me, these resistors should be connected to VCC.

with this configuration, we can have some issue ( I was in this case).After debug with a logic analyser, I saw only one clock, a beguining of transmission ( but without clock) and nothing else.

Just for testing, I removed these 2 resistors and it work fine

hope it will be useful

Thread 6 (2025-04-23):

read card issue

tcccorp, 2025-04-23:
hello,

Sometimes,  there is an issue when I want to read a card.   To make some debug, I wired UART to a buspirate .

With debug message I can see there is 26 bytes when everything is normal but sometimes, I don't know why yet, on the debug screen  I can see 1 bytes and after 25 bytes. So card is not recognized as espected. when this problem comes, it is more or less impossible to read other card, I have to restart the doorsim

I'll add some details soon I can !

If you have idea, Don't hesitate to share :)

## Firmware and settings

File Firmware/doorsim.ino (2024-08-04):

#include <Arduino.h>
#include <LiquidCrystal_I2C.h>
#include <DNSServer.h>
#include <WiFi.h>
#include <AsyncTCP.h>
#include "ESPAsyncWebServer.h"
#include <Preferences.h>
#include "AsyncJson.h"
#include "ArduinoJson.h"

AsyncWebServer server(80);
Preferences preferences;

// Set the LCD I2C address
LiquidCrystal_I2C lcd(0x20, 20, 4);

// general device settings
bool isCapturing = true;
String MODE; 

// card reader config and variables

// max number of bits
#define MAX_BITS 100
// time to wait for another weigand pulse
#define WEIGAND_WAIT_TIME 3000

// stores all of the data bits
volatile unsigned char databits[MAX_BITS];
volatile unsigned int bitCount = 0;

// stores the last written card's data bits
unsigned char lastWrittenDatabits[MAX_BITS];
unsigned int lastWrittenBitCount = 0;

// goes low when data is currently being captured
volatile unsigned char flagDone;

// countdown until we assume there are no more bits
volatile unsigned int weigandCounter;

// Display screen timer
unsigned long displayTimeout = 30000;  // 30 seconds
unsigned long lastCardTime = 0;
bool displayingCard = false;

// Wifi Settings
bool APMode;

// AP Settings
// ssid_hidden = broadcast ssid = 0, hidden = 1
// ap_passphrase = NULL for open, min 8 chars, max 63

String ap_ssid;
String ap_passphrase;
int ap_channel;
int ssid_hidden;

// Speaker and LED Settings
int spkOnInvalid;
int spkOnValid;
int ledValid;

// Custom Display Message
String customWelcomeMessage;
String welcomeMessageSelect;

// decoded facility code and card code
unsigned long facilityCode = 0;
unsigned long cardNumber = 0;

// hex data string
String hexCardData;

// raw data string
String rawCardData;
String status;
String details;


// store card data for later review
struct CardData {
  unsigned int bitCount;
  unsigned long facilityCode;
  unsigned long cardNumber;
  String hexCardData;
  String rawCardData;
  String status;   // Add status field
  String details;  // Add details field
};

// breaking up card value into 2 chunks to create 10 char HEX value
volatile unsigned long bitHolder1 = 0;
volatile unsigned long bitHolder2 = 0;
unsigned long cardChunk1 = 0;
unsigned long cardChunk2 = 0;

// Define reader input pins
// card reader DATA0
#define DATA0 19
// card reader DATA1
#define DATA1 18

//define reader output pins
// LED Output for a GND tie back
#define LED 32
// Speaker Output for a GND tie back
#define SPK 33

//define relay modules
#define RELAY1 25
#define RELAY2 26

// store card data for later review
struct Credential {
  unsigned long facilityCode;
  unsigned long cardNumber;
  char name[50]; // Use a fixed-size array for the name
};

const int MAX_CREDENTIALS = 100;
Credential credentials[MAX_CREDENTIALS];
int validCount = 0;

// maximum number of stored cards
const int MAX_CARDS = 100; 
CardData cardDataArray[MAX_CARDS];
int cardDataIndex = 0;

const char *index_html = R"rawliteral(
<!DOCTYPE html>
<html lang="en">
<head>
    <meta charset="UTF-8">
    <meta name="viewport" content="width=device-width, initial-scale=1.0">
    <title>Card Data</title>
    <style>
        body {
            font-family: Arial, sans-serif;
        }
        header {
            background-color: #333;
            color: white;
            padding: 10px;
            text-align: center;
        }
        header a {
            color: white;
            margin: 0 15px;
            text-decoration: none;
            cursor: pointer;
        }
        cardTable tbody:nth-child(2) {
           text-decoration: none;
           cursor: pointer;
           target: _blank;
        }
        a:hover {
            text-decoration: underline;
        }
        .content {
            padding: 20px;
        }
        table {
            width: 100%;
            border-collapse: collapse;
            margin-bottom: 20px;
        }
        th, td {
            padding: 8px;
            text-align: left;
            border-bottom: 1px solid #ddd;
        }
        th {
            background-color: #f2f2f2;
        }
        .hidden {
            display: none;
        }
        .collapsible {
            cursor: pointer;
        }
        .contentCollapsible {
            display: none;
            overflow: hidden;
        }
        .authorized {
            background-color: #90EE90;
        }
        .unauthorized {
            background-color: #FF4433;
        }
        .inputRow td {
            padding: 4px;
        }
        .inputRow input {
            width: 100%;
            box-sizing: border-box;
        }
    </style>
</head>
<body>
    <header>
        <a onclick="showSection('lastRead')">Last Read</a>
        <a onclick="showSection('ctfMode')">CTF Mode</a>
        <a onclick="showSection('settings')">Settings</a>
    </header>
    <div class="content">
        <div id="lastRead">
            <h1>Card Data</h1>
            <table id="cardTable">
                <thead>
                    <tr>
                        <th>#</th>
                        <th>Bit Length</th>
                        <th>Facility Code</th>
                        <th>Card Number</th>
                        <th>Hex Data</th>
                        <th>Raw Data</th>
                    </tr>
                </thead>
                <tbody>
                </tbody>
            </table>
        </div>
        <div id="ctfMode" class="hidden">
            <h1>CTF Mode</h1>
            <h2>Last Read Cards</h2>
            <table id="lastReadCardsTable">
                <thead>
                    <tr>
                        <th>#</th>
                        <th>Status</th>
                        <th>Details</th>
                    </tr>
                </thead>
                <tbody>
                </tbody>
            </table>
            <h2 class="collapsible" onclick="toggleCollapsible()">Card Data (click to expand/collapse)</h2>
            <div class="contentCollapsible">
                <table id="userTable">
                    <thead>
                        <tr>
                            <th>#</th>
                            <th>Facility Code</th>
                            <th>Card Number</th>
                            <th>Name</th>
                            <th>Action</th>
                        </tr>
                    </thead>
                    <tbody>
                    </tbody>
                </table>
                <textarea id="importExportArea" rows="4" cols="50"></textarea>
                <br>
                <button onclick="importData()">Import</button>
                <button onclick="exportData()">Export</button>
            </div>
        </div>
        <div id="settings" class="hidden">
            <h1>Settings</h1>
            <h2>General</h2>
            <label for="modeSelect">Mode:</label>
            <select id="modeSelect">
                <option value="DEMO">Demo</option>
                <option value="CTF">CTF</option>
            </select>
            <br><br>
            <label for="timeoutSelect">Display Timeout:</label>
            <select id="timeoutSelect">
                <option value="20000">20 seconds</option>
                <option value="30000">30 seconds</option>
                <option value="60000">1 minute</option>
                <option value="120000">2 minutes</option>
                <option value="0">Never</option>
            </select>
            <br><br>
            <h3>Wifi</h3>
            <div id="apSettings">
                <label for="ap_ssid">SSID:</label>
                <input type="text" id="ap_ssid">
                <br><br>
                <label for="ap_passphrase">Password:</label>
                <input type="text" id="ap_passphrase">
                <br><br>
                <label for="ssid_hidden">Hidden:</label>
                <input type="checkbox" id="ssid_hidden">
                <br><br>
                <label for="ap_channel">Channel:</label>
                <input type="number" id="ap_channel" min="1" max="12">
            </div>
            <br><br>
            <h2>CTF Mode</h2>
            <label for="welcomeMessageSelect">Welcome Message:</label>
            <select id="welcomeMessageSelect" onchange="toggleWelcomeMessage()">
                <option value="default">Default</option>
                <option value="custom">Custom</option>
            </select>
            <div id="customWelcomeMessage">
                <label for="customMessage">Custom Message:</label>
                <input type="text" id="customMessage" maxlength="20">
            </div>
            <br><br>
            <div>
                <label for="ledValid">On Valid Card - LED:</label>
                <select id="ledValid">
                    <option value="1">Flashing</option>
                    <option value="2">Solid</option>
                    <option value="0">Off</option>
                </select>
                <br><br>
                <label for="spkOnValid">On Valid Card - Speaker:</label>
                <select id="spkOnValid">
                    <option value="1">Pop Beeps</option>
                    <option value="2">Melody Beeps</option>
                    <option value="0">Off</option>
                </select>
            </div>
            <br><br>
            <div>
                <label for="spkOnInvalid">On Invalid Card - Speaker:</label>
                <select id="spkOnInvalid">
                    <option value=1>Sad Beeps</option>
                    <option value=0>Off</option>
                </select>
            </div>
            <br><br>
            <button onclick="saveSettings()">Save Settings</button>
        </div>
    </div>
    <script>
        let cardData = [];
        const tableBody = document.getElementById('cardTable').getElementsByTagName('tbody')[0];
        const userTableBody = document.getElementById('userTable').getElementsByTagName('tbody')[0];
        const lastReadCardsTableBody = document.getElementById('lastReadCardsTable').getElementsByTagName('tbody')[0];
        const importExportArea = document.getElementById('importExportArea');

        function updateTable() {
            fetch('/getCards')
                .then(response => response.json())
                .then(data => {
                    tableBody.innerHTML = '';
                    data.forEach((card, index) => {
                        cardData.push(card);
                        let row = tableBody.insertRow();
                        let cellIndex = row.insertCell(0);
                        let cellBitLength = row.insertCell(1);
                        let cellFacilityCode = row.insertCell(2);
                        let cellCardNumber = row.insertCell(3);
                        let cellHexData = row.insertCell(4);
                        let cellRawData = row.insertCell(5);

                        cellIndex.innerHTML = index + 1;
                        cellBitLength.innerHTML = card.bitCount;
                        cellFacilityCode.innerHTML = card.facilityCode;
                        cellCardNumber.innerHTML = card.cardNumber;
                        cellHexData.innerHTML = `<a href="#" onclick="copyToClipboard('${card.hexCardData}')">${card.hexCardData}</a>`;
                        cellRawData.innerHTML = card.rawCardData;
                    });
                })
                .catch(error => console.error('Error fetching card data:', error));
        }

        function updateUserTable() {
            fetch('/getUsers')
                .then(response => response.json())
                .then(data => {
                    userTableBody.innerHTML = '';
                    data.forEach((user, index) => {
                        let row = userTableBody.insertRow();
                        let cellIndex = row.insertCell(0);
                        let cellFacilityCode = row.insertCell(1);
                        let cellCardNumber = row.insertCell(2);
                        let cellName = row.insertCell(3);
                        let cellAction = row.insertCell(4);

                        cellIndex.innerHTML = index + 1;
                        cellFacilityCode.innerHTML = user.facilityCode;
                        cellCardNumber.innerHTML = user.cardNumber;
                        cellName.innerHTML = user.name;
                        cellAction.innerHTML = '<button onclick="deleteCard(' + index + ')">Delete</button>';
                    });

                    // Add input row at the bottom of the table
                    let inputRow = userTableBody.insertRow();
                    inputRow.className = 'inputRow';
                    let cellIndex = inputRow.insertCell(0);
                    let cellFacilityCode = inputRow.insertCell(1);
                    let cellCardNumber = inputRow.insertCell(2);
                    let cellName = inputRow.insertCell(3);
                    let cellAction = inputRow.insertCell(4);
                    
                    cellFacilityCode.innerHTML = '<input type="number" id="newFacilityCode">';
                    cellCardNumber.innerHTML = '<input type="number" id="newCardNumber">';
                    cellName.innerHTML = '<input type="text" id="newName">';
                    cellAction.innerHTML = '<button onclick="addCard()">Save</button>';
                })
                .catch(error => console.error('Error fetching user data:', error));
        }

        function updateLastReadCardsTable() {
            fetch('/getCards')
                .then(response => response.json())
                .then(data => {
                    lastReadCardsTableBody.innerHTML = '';
                    const last10Cards = data.slice(-10);
                    last10Cards.forEach((card, index) => {
                        let row = lastReadCardsTableBody.insertRow();
                        if (card.status === "Authorized") {
                            row.classList.add("authorized");
                        } else if (card.status === "Unauthorized") {
                            row.classList.add("unauthorized");
                        }
                        let cellIndex = row.insertCell(0);
                        let cellStatus = row.insertCell(1);
                        let cellDetails = row.insertCell(2);

                        cellIndex.innerHTML = index + 1;
                        cellStatus.innerHTML = card.status;
                        cellDetails.innerHTML = card.details;
                    });

                    // Add empty rows if there are less than 10 entries
                    for (let i = last10Cards.length; i < 10; i++) {
                        let row = lastReadCardsTableBody.insertRow();
                        let cellIndex = row.insertCell(0);
                        let cellStatus = row.insertCell(1);
                        let cellDetails = row.insertCell(2);

                        cellIndex.innerHTML = i + 1;
                        cellStatus.innerHTML = "";
                        cellDetails.innerHTML = "";
                    }
                })
                .catch(error => console.error('Error fetching last read card data:', error));
        }

        function addCard() {
            const facilityCode = document.getElementById('newFacilityCode').value;
            const cardNumber = document.getElementById('newCardNumber').value;
            const name = document.getElementById('newName').value;

            fetch(`/addCard?facilityCode=${facilityCode}&cardNumber=${cardNumber}&name=${name}`)
                .then(response => {
                    if (response.ok) {
                        updateUserTable();
                        alert('Card added successfully');
                    } else {
                        alert('Failed to add card');
                    }
                })
                .catch(error => console.error('Error adding card:', error));
        }

        function deleteCard(index) {
            fetch(`/deleteCard?index=${index}`)
                .then(response => {
                    if (response.ok) {
                        updateUserTable();
                        alert('Card deleted successfully');
                    } else {
                        alert('Failed to delete card');
                    }
                })
                .catch(error => console.error('Error deleting card:', error));
        }

        function showSection(section) {
            document.getElementById('lastRead').classList.add('hidden');
            document.getElementById('ctfMode').classList.add('hidden');
            document.getElementById('settings').classList.add('hidden');
            document.getElementById(section).classList.remove('hidden');
        }

        function toggleCollapsible() {
            const content = document.querySelector(".contentCollapsible");
            content.style.display = content.style.display === "block" ? "none" : "block";
        }

        function toggleWelcomeMessage() {
            const welcomeMessageSelect = document.getElementById('welcomeMessageSelect').value;
            const customMessageInput = document.getElementById('customMessage');
            if (welcomeMessageSelect === 'custom') {
                customMessageInput.disabled = false;
            } else {
                customMessageInput.disabled = true;
            }
        }

        function updateSettingsUI(settings) {
            document.getElementById('modeSelect').value = settings.mode;
            document.getElementById('timeoutSelect').value = settings.displayTimeout;
            document.getElementById('ap_ssid').value = settings.apSsid;
            document.getElementById('ap_passphrase').value = settings.apPassphrase;
            document.getElementById('ssid_hidden').checked = settings.ssidHidden;
            document.getElementById('ap_channel').value = settings.apChannel;
            document.getElementById('welcomeMessageSelect').value = settings.welcomeMessageSelect;
            document.getElementById('customMessage').value = settings.customMessage;
            document.getElementById('ledValid').value = settings.ledValid;
            document.getElementById('spkOnValid').value = settings.spkOnValid;
            document.getElementById('spkOnInvalid').value = settings.spkOnInvalid;
            toggleWifiSettings();
            toggleWelcomeMessage();
        }

        function saveSettings() {
            const mode = document.getElementById('modeSelect').value;
            const timeout = document.getElementById('timeoutSelect').value;
            const apSsid = document.getElementById('ap_ssid').value;
            const apPassphrase = document.getElementById('ap_passphrase').value;
            const ssidHidden = document.getElementById('ssid_hidden').checked;
            const apChannel = document.getElementById('ap_channel').value;
            const welcomeMessageSelect = document.getElementById('welcomeMessageSelect').value;
            const customMessage = document.getElementById('customMessage').value;
            const ledValid = document.getElementById('ledValid').value;
            const spkOnValid = document.getElementById('spkOnValid').value;
            const spkOnInvalid = document.getElementById('spkOnInvalid').value;

            let settings = {
                mode: mode,
                displayTimeout: parseInt(timeout, 10),
                apSsid: apSsid,
                apPassphrase: apPassphrase,
                ssidHidden: ssidHidden,
                apChannel: parseInt(apChannel),
                welcomeMessageSelect: welcomeMessageSelect,
                customMessage: customMessage,
                ledValid: parseInt(ledValid),
                spkOnValid: parseInt(spkOnValid),
                spkOnInvalid: parseInt(spkOnInvalid)
            };

            fetch('/saveSettings', {
                method: 'POST',
                headers: {
                    'Content-Type': 'application/json'
                },
                body: JSON.stringify(settings)
            })
            .then(response => {
                if (response.ok) {
                    alert('Settings saved successfully');
                } else {
                    alert('Failed to save settings');
                }
            })
            .catch(error => console.error('Error saving settings:', error));
        }

        function fetchSettings() {
            fetch('/getSettings')
                .then(response => response.json())
                .then(data => {
                    updateSettingsUI(data);
                })
                .catch(error => console.error('Error fetching settings:', error));
        }

        window.onload = fetchSettings;
        function exportData() {
            fetch('/getUsers')
                .then(response => response.json())
                .then(data => {
                    const dataString = JSON.stringify(data);
                    importExportArea.value = dataString;
                    importExportArea.select();
                    document.execCommand('copy');
                    alert('Data exported to clipboard');
                })
                .catch(error => console.error('Error exporting data:', error));
        }
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
void loop() {
  updateDisplay();

  if (!flagDone) {
    if (--weigandCounter == 0)
      flagDone = 1;
  }

  if (bitCount > 0 && flagDone) {
    if (!allBitsAreOnes()) {
      processCardData();
      if (bitCount >= 26 && bitCount <= 36 || bitCount == 96) {
        printCardData();
        printAllCardData();
      }
    }


    cleanupCardData();
    clearDatabits();
  }
}
